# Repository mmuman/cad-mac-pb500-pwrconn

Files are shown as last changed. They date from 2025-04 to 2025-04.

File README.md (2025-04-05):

# DIY Power Connector and USB-C adapter for PowerBook 500 Series

Copyright 2022-2025

Licence: CC-BY-NC-SA

## WARNING: Do NOT power Vbatt (pin 1) without a current limiter circuit, it will overheat the battery!!!

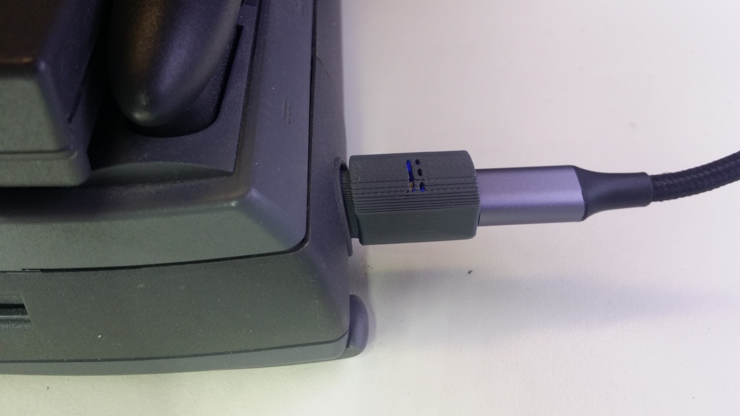
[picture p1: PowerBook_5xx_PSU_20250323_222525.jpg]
A tiny grey 3D-printed device with a USB-C cable plugged in, itself plugged into a PowerBook 520c power socket.


## References

- https://tinkerdifferent.com/threads/powerbook-5xx-usb-c-pd-adapter.4243/post-36576
- https://68kmla.org/bb/index.php?threads/powerbook-power-supply-connector-520-520c-540-540c.45148/post-558172

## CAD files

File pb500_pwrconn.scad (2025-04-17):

// DIY Power Connector for PowerBook 500 Series
//
// Copyright François Revol, 2022-2025
// Licenced under CC-BY-NC-SA

// WARNING: Do NOT power Vbatt (pin 1) without a current limiter circuit, it will overheat the battery!!!
// cf.
// https://tinkerdifferent.com/threads/powerbook-5xx-usb-c-pd-adapter.4243/post-36576
// https://68kmla.org/bb/index.php?threads/powerbook-power-supply-connector-520-520c-540-540c.45148/post-558172

/* [Variant] */

variant = 1; // [0:Connector,1:USB-C adapter,2:USB-C adapter + charge - UNIMPLEMENTED,3:USB-C adapter + voltmeter,4:USB-C adapter + charge + voltmeter - UNIMPLEMENTED]

/* [Options] */

// Make DC symbol hollow to see the LED through (hot glue makes for a nice light-pipe)
option_dc_symbol_hollow = false;

// Use a smaller USB-C decoy board (the one where the connector shell pins are flush with the PCB border (required unless with voltmeter variants)
option_usb_decoy_smaller = true;

// Add a way to pop the inner out for servicing
option_inner_removal_hole = true;

// Which font to pick the Apple logo from. Needs the proper font installed
option_apple_logo = 0; // [0: None, 1: San Francisco - the Real Deal on MacOS - UNTESTED, 2: Baskerville Old Face - on windows - UNTESTED, 3: Font Awesome 5 Brands - texlive-fonts-extra package on Debian, 4: ChicagoFLF - not exact, 5: GLYPHICONS Halflings - even less exact]

// Text on the side - Requires ChicagoFLF / Chicago font.
option_powerbook_text = true;

/* [Print options] */

// Print the inner contact block
print_inner = true;

// Show the shield in the preview
preview_shield = true;

// Print the connector shell
print_shell = true;

// Print the connector shell on the top side rather than over the cable end
rotate_shell = true;

/* [Model parameters] */

filament_lock = false;

contact_height = 15; //TODO: prefix dsub_
pb500_pwr_conn_height = 16;
pb500_pwr_conn_diam = 6.9;
pb500_pwr_conn_pitch = 2.7;
pb500_pwr_conn_pitch_fixup = 0.2;
pb500_pwr_conn_outer_margin = 0.0;
pb500_pwr_conn_contact_margin = 0.35;
pb500_pwr_conn_key_margin = 0.1;
pb500_pwr_conn_shell_margin = 0.4;

/* [Debug] */

debug = true;

preview = true;

// Radius on the shell body
smooth = 0.3; // [0.0:0.1:0.5]

// TODO: rename avoid_supports_z
avoid_supports = true;

// TODO: IMPLEMENT
avoid_supports_y = false;

// The type of shield we'll be using
shield_type = 1; // [0: Original - anyone seen one? - UNIMPLEMENTED, 1: Cheap RCA plug]

// BROKEN
option_angled = false;


/* [Hidden] */

//shield_margins = [0.4, 0.2];
//shield_margin = shield_margins[shield_type];


// we need more faces on such a small piece
$fa=6;
$fs=$preview?0.2:0.2;

appl_logo = [
    [/* none */],
    ["\uF8FF", "San Francisco"], // FIXME: UNTESTED - The official one
    ["\uF800", "Baskerville Old Face"], // FIXME: UNTESTED - on Windows
    ["\uF179", "Font Awesome 5 Brands"], // Most accurate but not very smooth
    ["\U01F34E", "ChicagoFLF"], // A bit too fat
    ["\uF8FF", "GLYPHICONS Halflings"] // Another plain apple.
];

module apple_logo(which=1, size=5) {
    text(appl_logo[which][0], font=appl_logo[which][1], valign="center", halign="center", size=size);
}



// TODO: use NopSCADlib's
module meter_3(segColor="Red", screw_holes=true, shorter=true) {
    pcb_w = shorter ? 22.7 : 24.7;
    color("DarkGreen") difference() {
        linear_extrude(0.9) difference() {
            //import("3_7seg_pcb-Edge_Cuts.svg");
            translate([32.75, 10.55]/2) {
                square([pcb_w,10.55], center=true);
                if (screw_holes) square([32.75,5], center=true);
            }
            for (d=[0,1]) translate([28*d+2.5,5]) circle(d=3);
        }
    }
    color("White") translate([5,0.1,0.9]) cube([22.7,10.1,6]);
    color("Black") translate([5,0.1,6.9]) cube([22.7,10.1,0.1]);
    color(segColor) translate([6-3,2,6.7]) text(" 1 5. 1", font="Ataxia BRK", size=7);
    //import("3_7seg_pcb-brd.svg");
}


module usb_decoy(smaller=true, o=0) {
    d = 2.5;
    shell_th = 0.5;
    conn_offset = smaller ? 1.5 : 1.2;
    pcb_bbox = (smaller ? [9.1, 1, 15.1] : [10.9, 1.5, 16.3]) + o*[1,5,1];
    // USB-C connector
    color("silver") {
        difference() {
            union() {
                hull() {
                    for (dy = [-1,1], dx = [-1,1])
                        translate([dx*(8.8-d)/2,dy*(3.1-d)/2,o ? -5 : 0]) cylinder(d=d+o*1.2, h=6.7+(o?10+o:0));
                }
                // ground pins
                translate([0,-1,6.7-4.5/2]) cube([8.8+o, 1.5, 4.5+o], center=true);
            }
            if (o == 0) hull() {
                for (dy = [-1,1], dx = [-1,1])
                    translate([dx*(8.8-d)/2,dy*(3-d)/2,-1]) cylinder(d=d-shell_th, h=6.7);
            }
        }
    }
    //translate([0,0,6.7/2]) cube([8.8, 3.1, 6.7], center=true);
    color("green") translate([0,5*o-(3.1+pcb_bbox.y)/2,15.1/2+conn_offset]) cube(pcb_bbox, center=true);
    // TODO: components
    /* does not seem to work */
    /*
    difference() {
        translate([-20,20-0.45]) import("USB-C_devoy_001.off");
        if (smaller) difference() {
            cube([25,20,10], center=true);
            translate([3.55,0,2.5]) cube([16.5,9.1,4.2], center=true);
        }
    }
    */
}


module dsub_contact_f(wire=0, margin = 0, c=0, cavity=false) {
    color(c?"gold":0) {
        // Simplified contact but that's way enough for our need
        translate([0,0,contact_height-5.5])
            difference() {
                union() {
                    cylinder(d=1.6+margin, h=5.3);
                    translate([0,0,4.99+0.3]) cylinder(d1=1.6+margin, d2=1.1+margin, h=0.2+margin/2);
                    // Cutout for the male pin
                    if (margin) translate([0,0,0.1]) cylinder(d=1.0+margin, h=10);
                }
                if (!margin) {
                    translate([0,0,0.1]) cylinder(d=0.7, h=10);
                    translate([0,0,1]) cube([2,0.3,9], center=true);
                    translate([0,0,5.3]) cylinder(d1=0.6, d2=1.3, h=0.3);
                }
            }
        translate([0,0,contact_height-5.5-2.2])
            cylinder(d1=2+margin,d2=1.6+margin, h=2.21+margin);
        translate([0,0,contact_height-9.4+1.75-0.3])
            cylinder(d1=2.1+margin,d2=2+margin, h=0.31+margin);
        translate([0,0,contact_height-9.4+0.3])
            cylinder(d=2.1+margin, h=1.75-0.6+margin);
        translate([0,0,contact_height-9.4-margin])
            cylinder(d1=2+margin,d2=2.1+margin, h=0.31+margin);
        // Crimping clips
        difference() {
            union() {
                if (margin) {
                    translate([0,0,contact_height-9.4-1-margin/2])
                        cylinder(d1=2.15+margin, d2=2.05, h=1.1+margin/2);
                    translate([0,0,contact_height-9.4-0.5-margin/2])
                        cube([1.7,1.7,1.2+margin/2],center=true);
                    /* XXX: results in "Normalized tree is growing past 200000 elements."
                    for (r = [0,90]) {
                        echo(r);
                        intersection() {
                            translate([0,0,contact_height-9.4-1])
                                cylinder(d=2, h=1.1);
                            translate([0,0,contact_height-9.4]) rotate([0,0,r]) cube([2,1,3], center=true);
                        }
                    }*/
                    translate([0,0,contact_height-9.4-4.7])
                        cylinder(d=2.1+margin, h=3.6);
                }
                translate([0,0,contact_height-9.4-1.2])
                    cylinder(d1=1.4,d2=1.46, h=1.2);
                translate([0.2,0,contact_height-9.4-1.2-2])
                    cylinder(d=1.4, h=2);
                translate([0,0,contact_height-9.4-4.7+1])
                    cylinder(d1=1.6, d2=1, h=1);
                translate([0,0,contact_height-9.4-4.7])
                    cylinder(d=1.6, h=1);
            }
            if (!margin) {
                translate([0,0,contact_height-9.4-5]) cylinder(d=1, h=5);
                translate([1,0,contact_height-9.4-5]) cube([2,0.3,9], center=true);
                //translate([0,0,5.3]) cylinder(d1=0.6, d2=1.1, h=0.3);
            }
        }

        if (margin)
            translate([0,0,-10])
                cylinder(d=2.1+margin, h=10+contact_height-9.4-4.7+0.1);
    }
    // the wire
    color(c?"silver":0)
        translate([0,0,4.3]) rotate([180,0,0]) cylinder(d = 0.8+margin, h = wire + 2.2);
    color(c) {
        translate([0,0,2]) rotate([180,0,0]) cylinder(d = 1.5+margin, h = wire);
    }
}


module pb500_pwr_conn_inner(preview=true) {
    height = pb500_pwr_conn_height;
    pitch = pb500_pwr_conn_pitch + pb500_pwr_conn_pitch_fixup;
    diam = pb500_pwr_conn_diam;
    outer_margin = pb500_pwr_conn_outer_margin;
    contact_margin = pb500_pwr_conn_contact_margin;
    contact_z_offset = 0.5;

    wire_colors = ["red", "orange", "blue", "black"];
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

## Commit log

2023-02-19 Work in progress for a PowerBook 5xx power connector
    Gave up using Dupont female pins: too large case, and not suited to high
    current anyway.
    Currently looking into D-Sub contacts.
    [pb500_pwrconn.scad]
2023-02-19 Rework pin and key placement
    Just makes the code simpler.
    [pb500_pwrconn.scad]
2023-02-19 Add pin labels
    [pb500_pwrconn.scad]
2023-02-19 Drop unused dupont stuff
    [pb500_pwrconn.scad]
2023-02-19 Some adjustments
    [pb500_pwrconn.scad]
2023-02-20 First version of the shell
    [pb500_pwrconn.scad]
2023-02-20 Add the cable clip
    [pb500_pwrconn.scad]
2023-02-23 First working version
    Not ready for production yet but it fits.
    [pb500_pwrconn.scad]
2023-02-23 Fix pin insertion hole
    [pb500_pwrconn.scad]
2023-02-26 Add shield, as scavenged from RCA jacks
    [pb500_pwrconn.scad]
2023-02-27 Fix inner and shell parts to accomodate the RCA shield
    [pb500_pwrconn.scad]
2023-02-27 Optionally rotate the shell for printing
    [pb500_pwrconn.scad]
2023-03-06 Give some more room around the shield
    [pb500_pwrconn.scad]
2023-03-06 Cleanup; add a preview_shield option
    [pb500_pwrconn.scad]
2025-03-25 A working version of a USB-C adapter
    [pb500_pwrconn.scad]
2025-04-05 An untested variant with 7-segment voltmeter display
    Why do people like these things… oh well.
    [pb500_pwrconn.scad]
2025-04-05 Mention licence explicitly
    [pb500_pwrconn.scad]
2025-04-05 Optional Apple logo
    [pb500_pwrconn.scad]
2025-04-05 Fix cable clip removal for longer shells
    [pb500_pwrconn.scad]
2025-04-05 Mention "PowerBook 5xx"
    Though smaller shells miss the 5xx but well.
    [pb500_pwrconn.scad]
2025-04-05 Add Vbatt warning and references
    [pb500_pwrconn.scad]
2025-04-05 Update debug cut
    [pb500_pwrconn.scad]
2025-04-05 Unfinished angled option
    Wouldn't look as stylish anyway if you ask me.
    [pb500_pwrconn.scad]
2025-04-05 Make the inner part 0.1mm larger, avoids haivng it hollow with FDM
    The original is actually as thick anyway.
    [pb500_pwrconn.scad]
2025-04-06 A lot of tweaks to make assembly easier
    Close to production level.
    [pb500_pwrconn.scad]
2025-04-06 Some more tweaks
    Much easier to assemble now.
    [pb500_pwrconn.scad]
2025-04-17 Make the Apple logo configurable depending on the font you have
    cf. for Windows:
    https://superuser.com/questions/1205451/how-can-i-display-the-uf8ff-apple-logo-character-on-windows
    [pb500_pwrconn.scad]
2025-04-17 Add an option for a "PowerBook" text on the side
    [pb500_pwrconn.scad]
